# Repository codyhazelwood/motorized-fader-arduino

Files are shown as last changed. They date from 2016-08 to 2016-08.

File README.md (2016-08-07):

# Motorized Fader and MIDI Control Project

Code, schematics, and helpful MIDI spec for these projects:

- [Motorized Faders and the Arduino](http://blog.codyhazelwood.me/motorized-faders-and-the-arduino/)
- [MIDI Control with an Arduino and a Motorized Fader](http://blog.codyhazelwood.me/midi-control-with-an-arduino-and-a-motorized-fader/)

These projects were completed for my Computer Science Microcontrollers class at Middle Tennessee State University in 2012.  Refer to the links above for more information.

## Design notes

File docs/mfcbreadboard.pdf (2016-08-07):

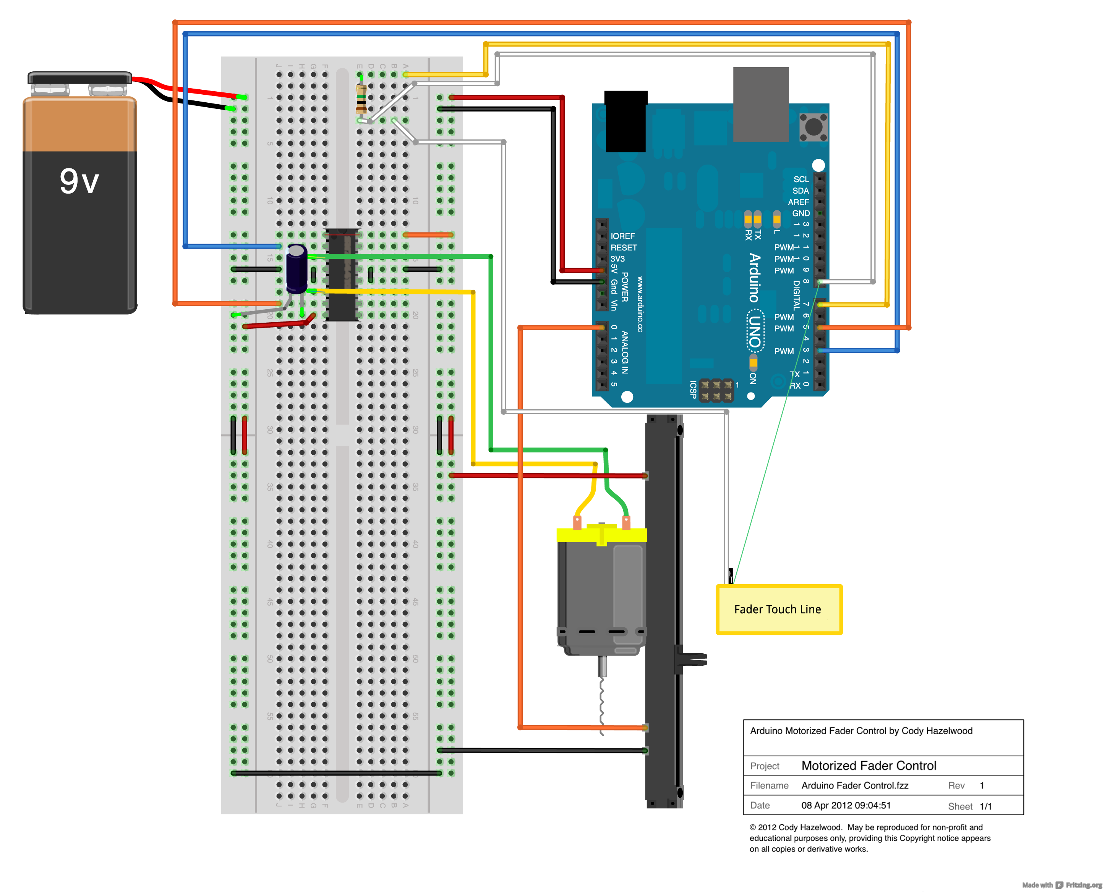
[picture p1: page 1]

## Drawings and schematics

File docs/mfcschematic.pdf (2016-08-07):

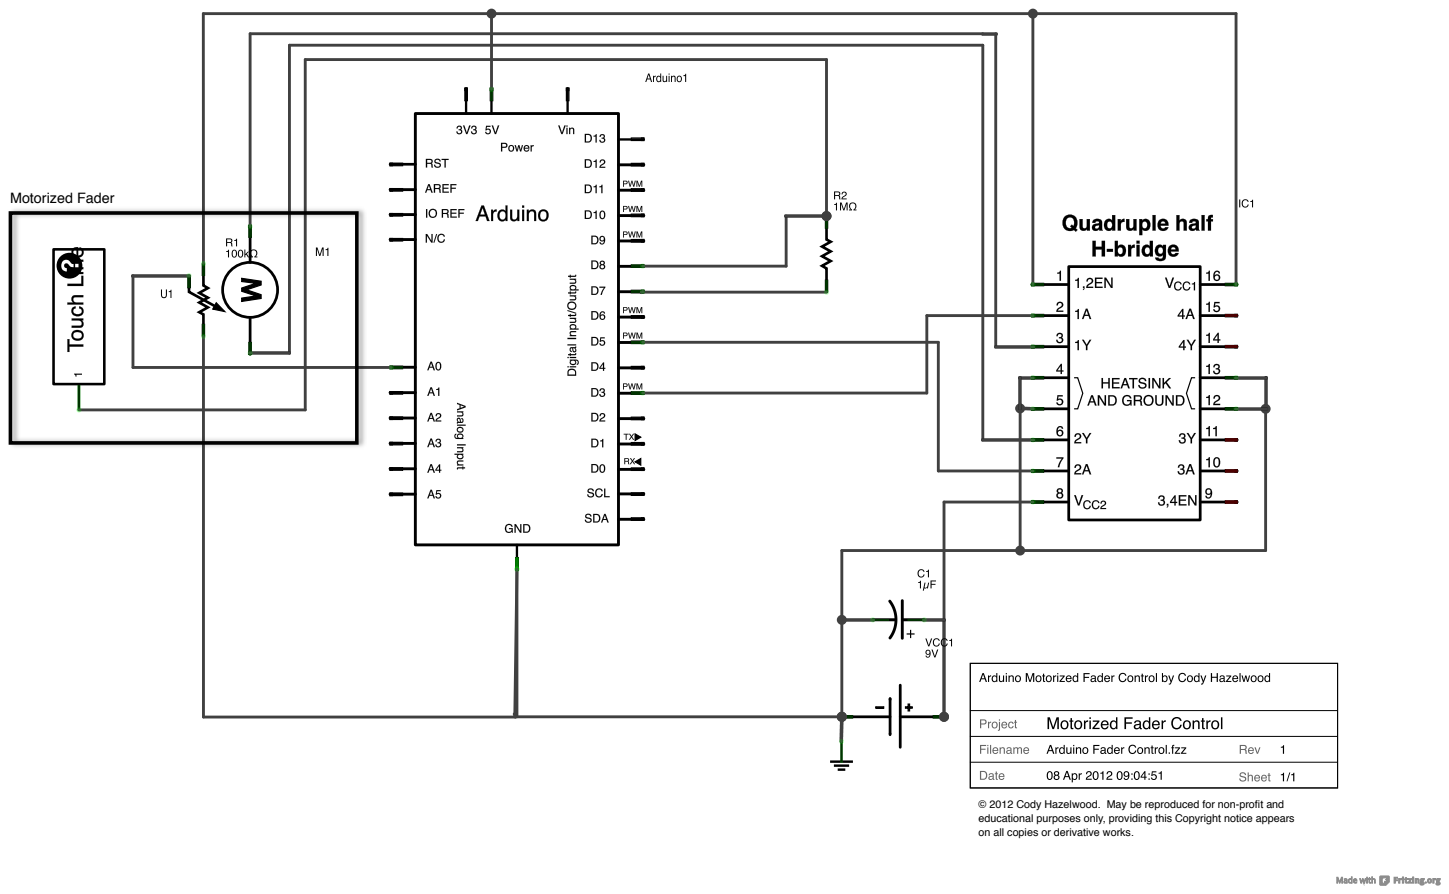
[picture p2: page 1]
Motorized Fader

© 2012 Cody Hazelwood. May be reproduced for non-profit and
educational purposes only, providing this Copyright notice appears
on all copies or derivative works.

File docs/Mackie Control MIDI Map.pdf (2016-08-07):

# Own a Mackie Control?

# Do you want to know what it's saying to your computer?

I am the happy owner of a Mackie Control, control surface.
I use mine for Mark of the Unicorn's Digital Performer

Mackie provided no MIDI implementation chart, or any other hints about remapping the controls.

Imagine my frustration, when I wanted to map a couple of control pedals in for specific DP functions (Play and Punch).

Having mapped out what MIDI messages it sends for all the knows and buttons, I though I would share. So....

I have divided the control surface into areas in an attempt to simply locating a particular control's information.
The positional data is (more or less) starting in the upper left hand corner of an area.

Notes:
CW = ClockWise rotation of a rotary encoder (VPot or Scrub Wheel). Translation: message sent when turning it "up"
CCW = Counter ClockWise rotation of a rotary encoder (VPot or Scrub Wheel). Translation: message sent when turning it "down."
When the VPots are rotated rapidly CW, a message equal to the number of clicks is sent.
When the VPots are rotated rapidly CCW, a "65" is sent followed by a message equal to the number of clicks is sent. Think of 65 as "sign indicator."

The Zero label at middle of fader travel = zero in Pitch Wheel Position data.

The Red Area has different labels (lexan overlays) depending on the DAW to which the Mackie Control is attached. See the note at the Red Area table.

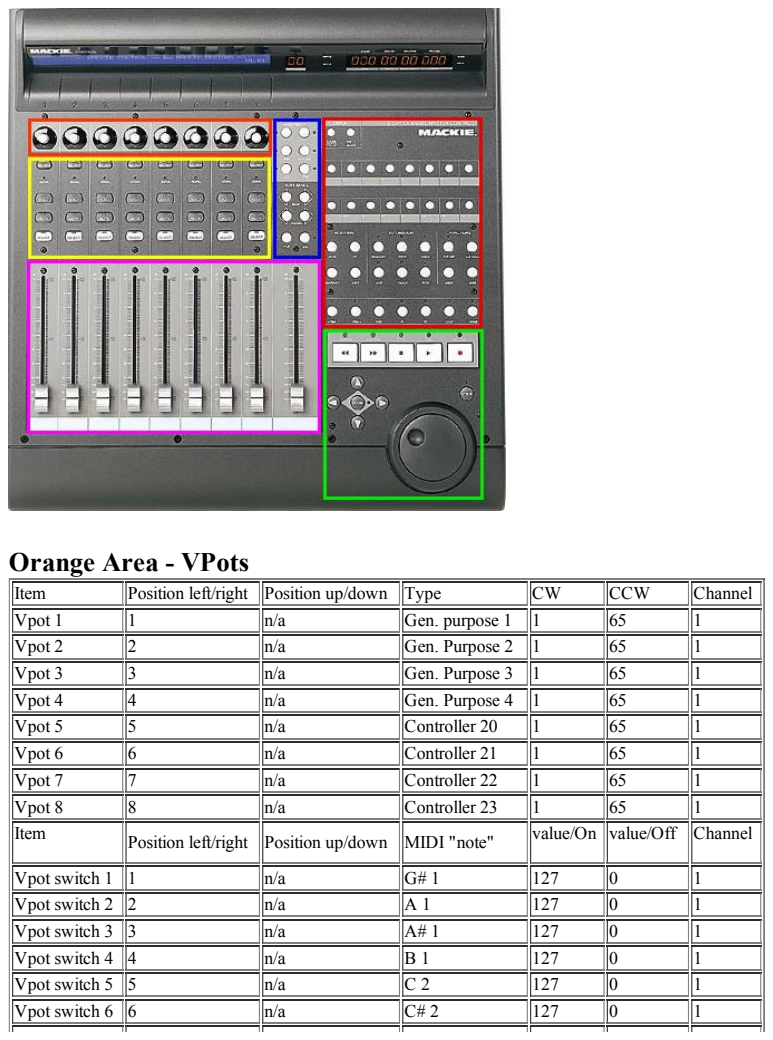
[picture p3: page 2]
Item; Position left/right; Position up/down; Type; CCW; Channel; Vpot 1; Gen. purpose 1; Vpot 2; Gen. Purpose 2; Vpot 3; Gen. Purpose 3; Vpot 4; Gen. Purpose 4; Vpot 5; Controller 20; Vpot 6; Controller 21; Vpot 7; Controller 22; Vpot 8; Controller 23; MIDI "note"; value/On; value/Off; Vpot switch 1; Vpot switch 2; Vpot switch 3; Vpot switch 4; Vpot switch 5; Vpot switch 6

Orange Area - VPots

## Yellow Area - Channel switches

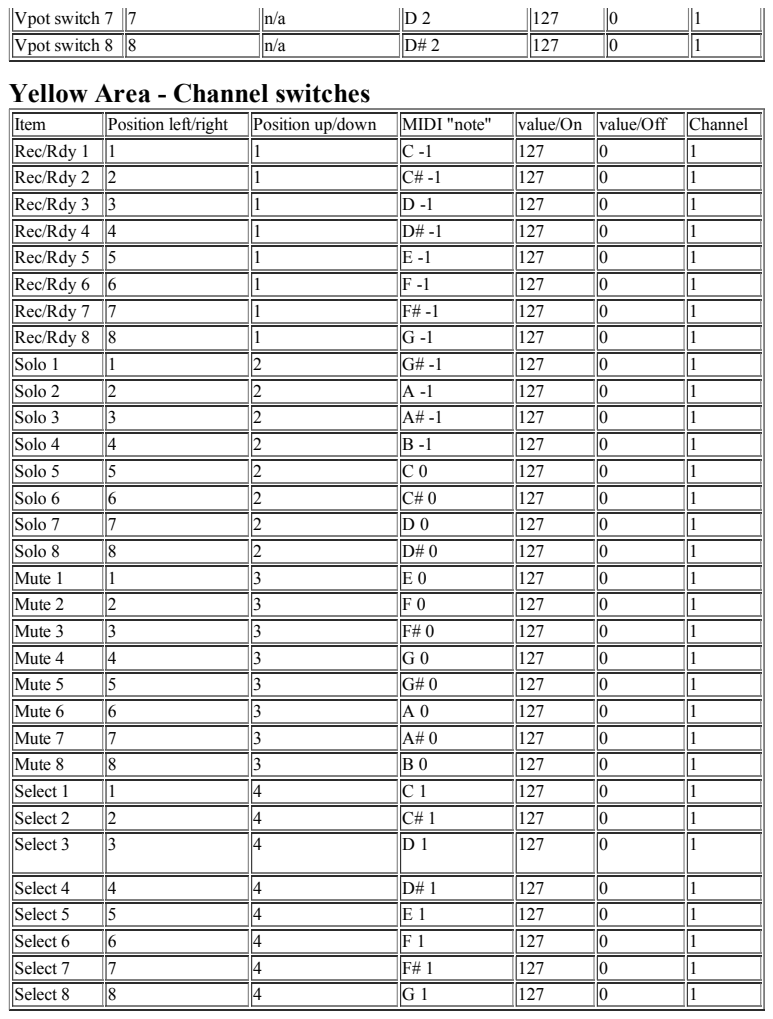
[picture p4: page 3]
Vpot switch 7; Vpot switch 8; Item; Position left/right; Position up/down; MIDI "note"; value/On; value/Off; Channel; Rec/Rdy 1; Rec/Rdy 2; Rec/Rdy 3; Rec/Rdy 4; Rec/Rdy 5; Rec/Rdy 6; Rec/Rdy 7; Rec/Rdy 8; Solo 1; Solo 2; Solo 3; Solo 4; Solo 5; Solo 6; Solo 7; Solo 8; Mute 1; Mute 2; Mute 3; Mute 4; Mute 5; Mute 6; Mute 7; Mute 8; Select 1; Select 2; Select 3; Select 4; Select 5; Select 6; Select 7; Select 8

## Lavender Area - Faders

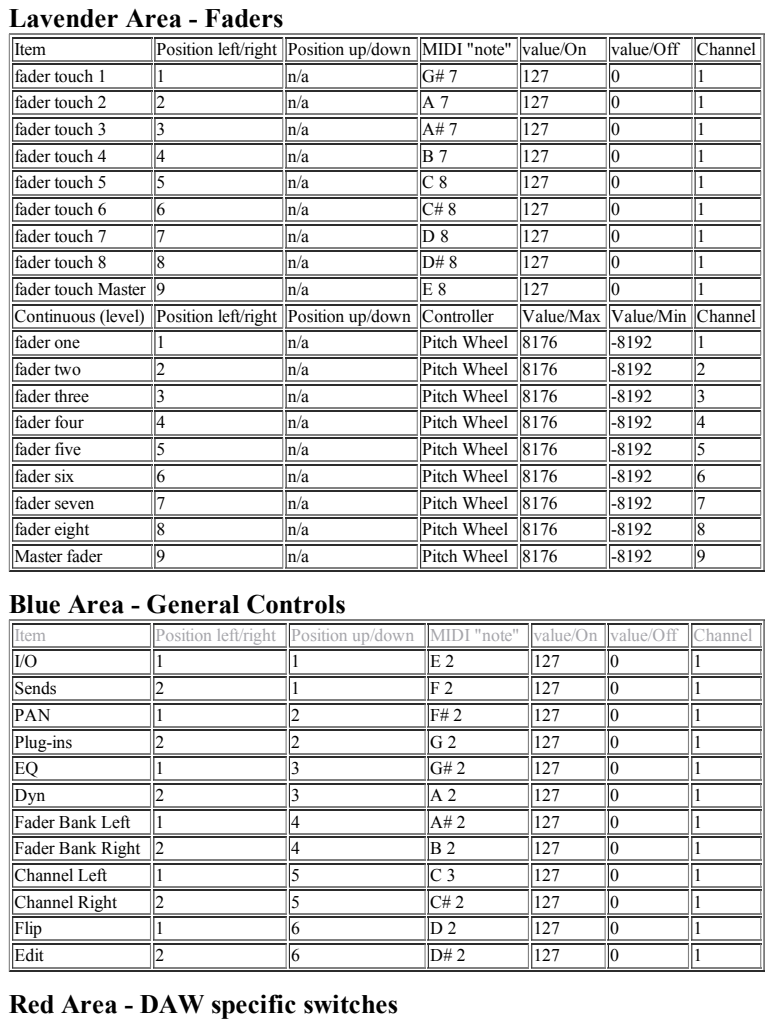
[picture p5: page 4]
Item; Position left/right; Position up/down; MIDI "note"; value/On; value/Off; Channel; fader touch 1; fader touch 2; fader touch 3; fader touch 4; fader touch 5; fader touch 6; fader touch 7; fader touch 8; fader touch Master; Continuous (level); Controller; Value/Max; Value/Min; fader one; Pitch Wheel; fader two; fader three; fader four; fader five; fader six; fader seven; fader eight; Master fader; Sends; PAN; Plug-ins; Dyn; Fader Bank Left; Fader Bank Right; Channel Left; Channel Right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

Blue Area - General Controls
Red Area - DAW specific switches

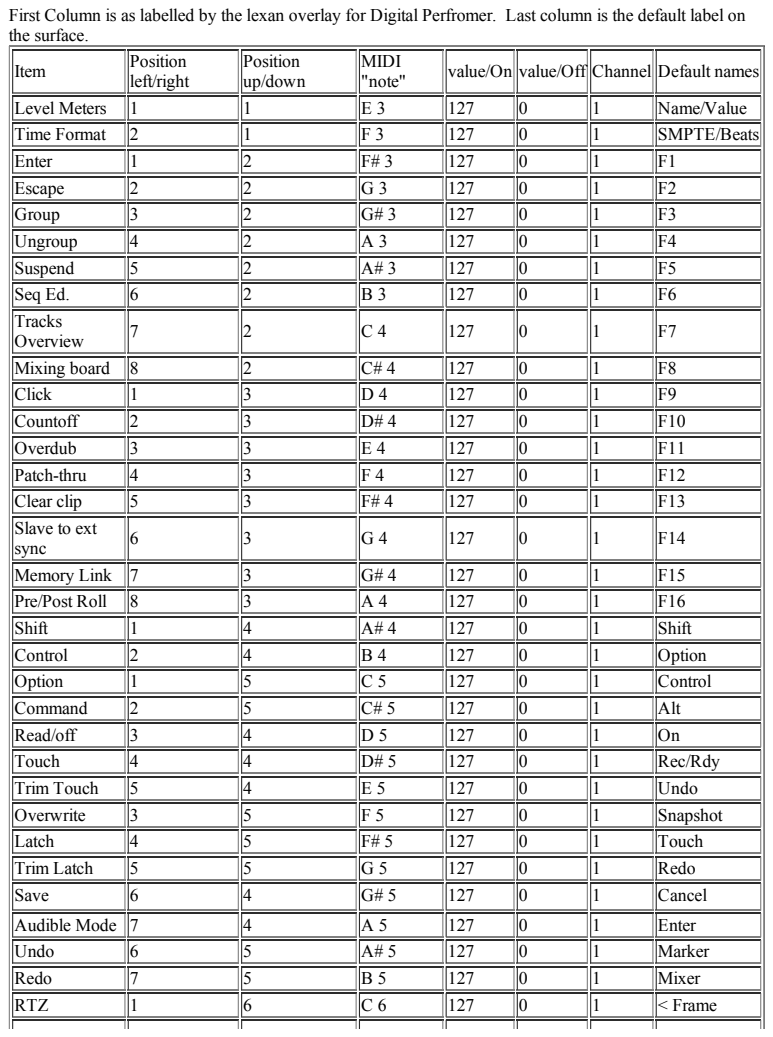
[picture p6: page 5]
Position left/right; Position up/down; MIDI; "note"; value/On; value/Off Channel; Default names; Level Meters; Name/Value; Time Format; SMPTE/Beats; Enter; Escape; Group; Ungroup; Suspend; Seq Ed.; Mixing board; Click; Countoff; Overdub; Patch-thru; Clear clip; Memory Link; Pre/Post Roll; Shift; Control; Option; Command; Alt; Read/off; Touch; Rec/Rdy; Trim Touch; Undo; Overwrite; Snapshot; Latch; Trim Latch; Redo; Save; Cancel; Audible Mode; Marker; Mixer; RTZ; < Frame

First Column is as labelled by the lexan overlay for Digital Perfromer. Last column is the default label on
the surface.
Item
Tracks
Overview
Slave to ext
sync

## Green Area - Transport and Navigation controls

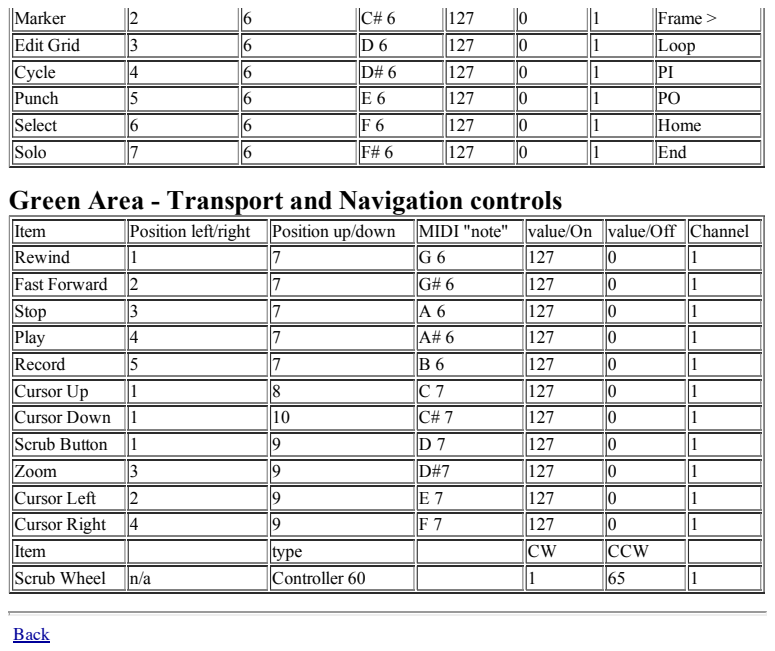
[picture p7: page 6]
Marker; Frame >; Edit Grid; Loop; Cycle; Punch; Select; Home; Solo; End; Item; Position left/right; Position up/down; MIDI "note"; value/On; value/Off; Channel; Rewind; Fast Forward; Stop; Play; Record; Cursor Up; Cursor Down; Scrub Button; Zoom; Cursor Left; Cursor Right; type; CCW; Scrub Wheel; Controller 60; Back

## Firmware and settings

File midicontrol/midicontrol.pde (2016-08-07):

/* -----------------------------------------------------------------------
 * Programmer:   Cody Hazelwood
 * Date:         May 17, 2012
 * Platform:     Arduino Uno
 * Description:  MIDI controller using a motorized fader and an Arduino
 * Dependencies: CapSense Arduino Library (for fader touch sensitivity)
 *               http://www.arduino.cc/playground/Main/CapSense
 *               MIDI Library for Arduino
 *               http://www.arduino.cc/playground/Main/MIDILibrary
 * -----------------------------------------------------------------------
 * Copyright (c) 2012 Cody Hazelwood
 *
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
 * THE SOFTWARE IS PROVIDED "AS IS", WITHOUT WARRANTY OF ANY KIND, EXPRESS OR
 * IMPLIED, INCLUDING BUT NOT LIMITED TO THE WARRANTIES OF MERCHANTABILITY,
 * FITNESS FOR A PARTICULAR PURPOSE AND NONINFRINGEMENT. IN NO EVENT SHALL THE
 * AUTHORS OR COPYRIGHT HOLDERS BE LIABLE FOR ANY CLAIM, DAMAGES OR OTHER
 * LIABILITY, WHETHER IN AN ACTION OF CONTRACT, TORT OR OTHERWISE, ARISING
 * FROM, OUT OF OR IN CONNECTION WITH THE SOFTWARE OR THE USE OR OTHER DEALINGS
 * IN THE SOFTWARE.
 * -----------------------------------------------------------------------
 * -----------------------------------------------------------------------
 */

 /************************************************************************
  *   Currently known issues:
  *
  *   *  Only DAW Channels 1-8 work right now
  *   *  Better Fader Calibration is needed
  *   *  Doesn't work with Pro Tools due to Avid's restrictions (but any
  *         other DAW that supports Mackie Control without HUI support will
  *         work fine (Cubase, Logic, Digital Performer, Live, etc.)
  *
  *************************************************************************/

#include <CapSense.h>         //Library for fader touch sensitivity
#include <MIDI.h>             //Library for receiving MIDI messages

//Arduino Pin Assignments
const int motorDown    = 5;   //H-Bridge control to make the motor go down
const int motorUp      = 6;   //H-Bridge control to make the motor go up

//Inputs
const int wiper        = 0;   //Position of fader relative to GND (Analog 0)
const int touchSend    = 7;   //Send pin for Capacitance Sensing Circuit (Digital 7)
const int touchReceive = 8;   //Receive pin for Capacitance Sensing Circuit (Digital 8)

//Variables
double   faderMax        = 0;     //Value read by fader's maximum position (0-1023)
double   faderMin        = 0;     //Value read by fader's minimum position (0-1023)
int      faderChannel    = 1;     //Value from 1-8
bool     touched         = false; //Is the fader currently being touched?
bool     positionUpdated = false; //Since touching, has the MIDI position been updated?

CapSense touchLine     = CapSense(touchSend, touchReceive);

void setup() {
    MIDI.begin(MIDI_CHANNEL_OMNI);  //Receive messages on all MIDI channels
    MIDI.turnThruOff();             //We don't need MIDI through for this

    pinMode (motorUp, OUTPUT);
    pinMode (motorDown, OUTPUT);

    calibrateFader();

    attachInterrupt(0, nextChannel, RISING);
    attachInterrupt(1, prevChannel, RISING);
}

void loop() {
    /* If there is a MIDI message waiting, and it is for the currently selected
       fader, and it is a PitchBend message (used for fader control), then convert
       the PitchBend value and update the fader's current position.  */
    if (MIDI.read() && MIDI.getChannel() == faderChannel && MIDI.getType() == PitchBend ) {
        /* Bitwise math to take two 7 bit values for the PitchBend and convert to
           a single 14 bit value.  Then converts it to value between 0 and 1023
           to control the fader. */
        int value = (((MIDI.getData2() << 7) + MIDI.getData1()) * 0.0625);
        updateFader(value);
    }

    checkTouch();  //Checks to see if the fader is being touched

    //If the fader has been touched, it needs to update the position on the MIDI host
    if (!positionUpdated) {
        updateFaderMidi();
        positionUpdated = true;
    }
}

void updateFaderMidi() {
    int  velocity    = faderPosition();
    byte channelData = 0xE0 + (faderChannel - 1);
                                             // MIDI Message:
    Serial.write(channelData);               //  E(PitchBend)  Channel (0-9)
    Serial.write(velocity & 0x7F);           //  Least Sig Bits of Data
    Serial.write((velocity >> 7) & 0x7F);    //  Most  Sig Bits of Data
}

//Calibrates the min and max position of the fader
void calibrateFader() {
    //Send fader to the top and read max position
    digitalWrite(motorUp, HIGH);
    delay(250);
    digitalWrite(motorUp, LOW);
    faderMax = analogRead(wiper) - 5;

    //Send fader to the bottom and read min position
    digitalWrite(motorDown, HIGH);
    delay(250);
    digitalWrite(motorDown, LOW);
    faderMin = analogRead(wiper) + 5;
}

//Returns a MIDI pitch bend value for the fader's current position
//Cases ensure that there is a -infinity (min) and max value despite possible math error
int faderPosition() {
    int position = analogRead(wiper);
    int returnValue = 0;

    if (position <= faderMin) {
        returnValue = 0;
    }
    else if (position >= faderMax) {
        returnValue = 16383;
    }
    else {
        returnValue = ((float)(position - faderMin) / (faderMax - faderMin)) * 16383;
    }

    return returnValue;
}

//Check to see if the fader is being touched
void checkTouch() {
    //For the capSense comparison below,
    //700 is arbitrary and may need to be changed
    //depending on the fader cap used (if any).

    if (!touched && touchLine.capSense(30) >= 700) {
        touched = true;

        //Send MIDI Touch On Message
        Serial.write(0x90);
        Serial.write(0x67 + faderChannel);
        Serial.write(0x7f);
    }
    else if (touched && touchLine.capSense(30) < 700) {
        touched = false;

        //Send MIDI Touch Off Message
        Serial.write(0x90);
        Serial.write(0x67 + faderChannel);
        Serial.write((byte) 0x00);
    }

    if (touched) {
        positionUpdated = false;
    }
}

//Function to move fader to a specific position between 0-1023 if it's not already there
void updateFader(int position) {
    if (position < analogRead(wiper) - 10 && position > faderMin && !touched) {
        digitalWrite(motorDown, HIGH);
        while (position < analogRead(wiper) - 10 && !touched) {};  //Loops until motor is done moving
        digitalWrite(motorDown, LOW);
    }
    else if (position > analogRead(wiper) + 10 && position < faderMax && !touched) {
        digitalWrite(motorUp, HIGH);
        while (position > analogRead(wiper) + 10 && !touched) {}; //Loops until motor is done moving
        digitalWrite(motorUp, LOW);
    }
}

//Selects the next channel in the DAW
void nextChannel() {
    static unsigned long last_interrupt0_time = 0;      //Interrupt Debouncing
    unsigned long interrupt0_time = millis();           //Interrupt Debouncing

    if (interrupt0_time - last_interrupt0_time > 200) { //Interrupt Debouncing
        if (faderChannel < 8) {
            faderChannel++;

            Serial.write(0x90);
            Serial.write(0x17 + faderChannel);
            Serial.write(0x7f);                         //Note On
            Serial.write(0x90);
            Serial.write(0x17 + faderChannel);
            Serial.write((byte) 0x00);                    //Note Off
        }
    }

    last_interrupt0_time = interrupt0_time;             //Interrupt Debouncing
}

//Selects the previous channel in the DAW
void prevChannel() {
    static unsigned long last_interrupt1_time = 0;      //Interrupt Debouncing
    unsigned long interrupt1_time = millis();           //Interrupt Debouncing

    if (interrupt1_time - last_interrupt1_time > 200) { //Interrupt Debouncing
        if (faderChannel > 1) {
            faderChannel--;

            Serial.write(0x90);
            Serial.write(0x17 + faderChannel);
            Serial.write(0x7f);                         //Note On
            Serial.write(0x90);
            Serial.write(0x17 + faderChannel);
            Serial.write((byte) 0x00);                    //Note Off
        }
    }

    last_interrupt1_time = interrupt1_time;             //Interrupt Debouncing
}
